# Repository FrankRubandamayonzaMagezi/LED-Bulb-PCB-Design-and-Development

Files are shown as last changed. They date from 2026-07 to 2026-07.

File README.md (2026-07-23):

# LED Bulb PCB Design and Development

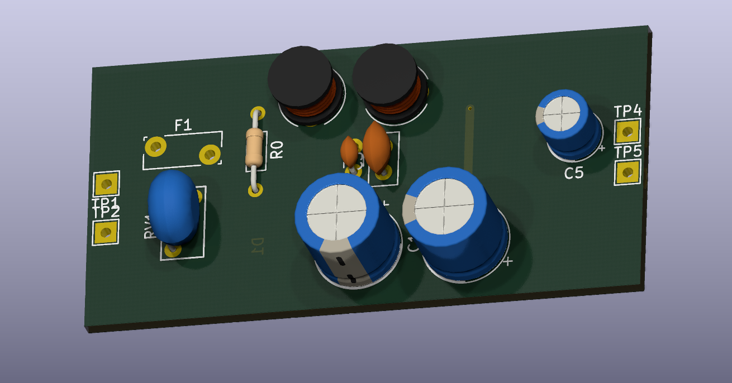
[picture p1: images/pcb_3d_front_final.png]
Final PCB 3D View


## Project Overview

This repository documents the design and development of a **5 W, 240 VAC LED bulb PCB**. The project follows the complete engineering workflow from schematic capture and PCB layout to simulation, PCB manufacturing, assembly and hardware testing.

The aim is to design an affordable, reliable and energy-efficient LED bulb suitable for indoor lighting while gaining practical experience in professional PCB design and electronics manufacturing.

---

## Project Objectives

The objectives of this project are to:

- Design a production-ready PCB for a 5 W LED bulb.
- Develop a complete schematic using KiCad.
- Assign footprints to all electronic components.
- Produce a manufacturable PCB layout.
- Simulate the LED bulb power supply using Proteus.
- Generate Gerber files for PCB fabrication.
- Manufacture and assemble the PCB.
- Test and evaluate the final LED bulb.
- Document every stage of the engineering process.

---

## Current Progress

- ✅ Schematic design completed
- ✅ Component footprint assignment completed
- ✅ PCB routing completed
- ✅ 3D PCB verification completed
- ✅ AC-to-DC bridge rectifier simulation completed
- ✅ Gerber generation
- 🔄 PCB fabrication (Training completed- LED bulb PCB fabrication in progress)
- 🔄 Component assembly
- ⏳ Hardware testing
- ⏳ Final product evaluation

---

## Design Specifications

- **Product:** 5 W LED Bulb
- **Input Voltage:** 240 VAC
- **Frequency:** 50 Hz
- **Application:** Indoor Lighting
- **PCB Design Software:** KiCad 10
- **Simulation Software:** Proteus 8 Professional

---

## Skills Demonstrated

This project demonstrates practical experience in:

- PCB schematic capture
- PCB layout design
- Component footprint assignment
- PCB routing
- Electrical Rule Check (ERC)
- Design Rule Check (DRC)
- PCB 3D verification
- Circuit simulation using Proteus
- Power electronics
- PCB fabrication techniques
- Electronics manufacturing
- Git and GitHub version control
- Engineering documentation

---

## Repository Structure

```
LED-Bulb-PCB-Design-and-Development/
│
├── docs/
├── fabrication/
├── footprints/
├── images/
├── pcb/
├── schematic/
├── simulations/
├── symbols/
├── README.md
└── .gitignore
```

---

## Design Workflow

The project follows the following engineering workflow:

1. Component selection
2. Schematic capture
3. Footprint assignment
4. Electrical Rule Check (ERC)
5. PCB layout
6. Component placement
7. PCB routing
8. Design Rule Check (DRC)
9. 3D PCB verification
10. Circuit simulation
11. Gerber generation
12. PCB fabrication
13. PCB assembly
14. Hardware testing
15. Final product evaluation

---

## Components Used

The current design includes:

- MP4050G LED Driver IC
- MB10S Bridge Rectifier
- Fuse
- Electrolytic Capacitors
- Ceramic Capacitors
- Resistors
- LEDs
- AC Input Connector
- PCB Connectors

---

## Proteus Simulation

A Proteus simulation was developed to demonstrate the **AC-to-DC rectification stage** of the LED bulb power supply.

The simulation includes:

- 240 VAC AC source
- Fuse
- Full bridge rectifier
- Electrolytic smoothing capacitor
- Current-limiting resistor
- LED load
- AC voltmeter
- DC voltmeter
- DC ammeter
- Oscilloscope

### Simulation Results

The following measurements were obtained during simulation:

- AC input voltage: **Approximately 241 VAC**
- DC output voltage: **Approximately 338 VDC**
- LED current: **Approximately 4.19 mA**

The simulation confirms successful AC-to-DC conversion and demonstrates the operation of the rectification stage.

> **Note**
>
> The production LED bulb uses the **MP4050G LED Driver IC**. Since a compatible Proteus simulation model is currently unavailable, the simulation focuses on demonstrating the AC-to-DC rectification stage rather than the complete LED driver circuit.

---

## Oscilloscope Waveform Verification

An oscilloscope was connected during the Proteus simulation to observe the AC input and the rectified DC output of the bridge rectifier. The captured waveforms verify the AC-to-DC conversion process by showing the sinusoidal AC input and the rectified DC output before filtering and after filtering. This confirms the correct operation of the bridge rectifier and smoothing capacitor before the power is supplied to the LED load.

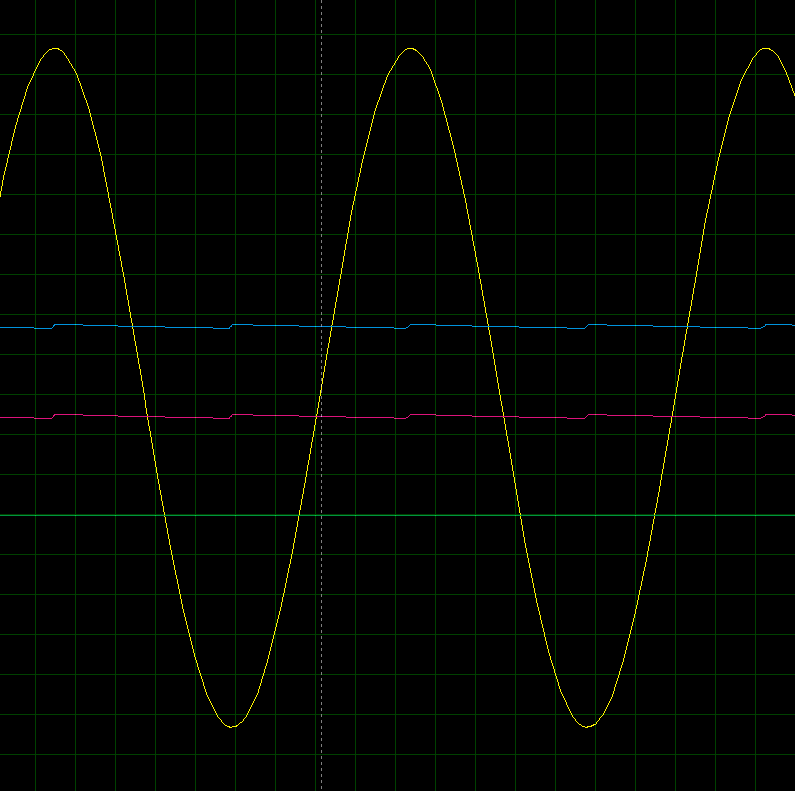
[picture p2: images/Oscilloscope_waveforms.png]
Oscilloscope Waveform Analysis


---

# Project Gallery

## Schematic Diagram

Complete schematic designed in KiCad.

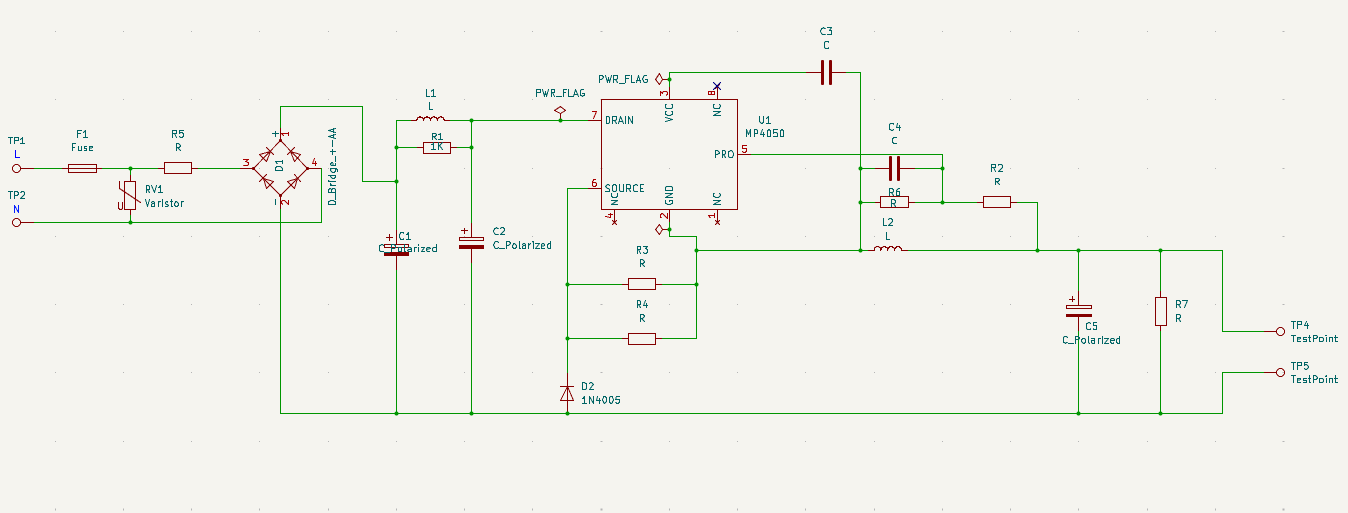
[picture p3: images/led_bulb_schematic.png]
Schematic


---

## Initial PCB Layout

First routed PCB layout.

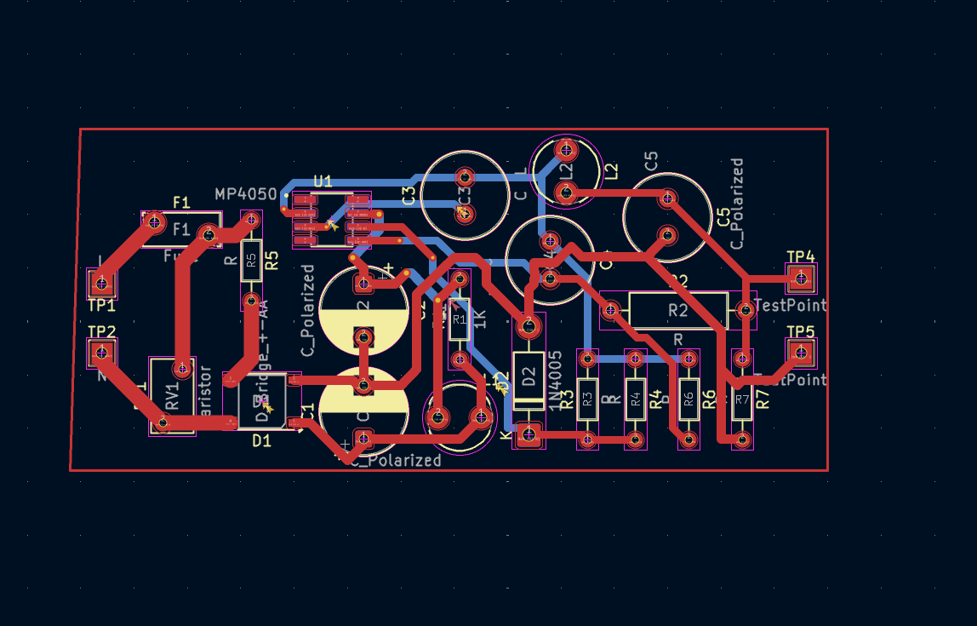
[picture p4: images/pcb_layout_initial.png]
Initial PCB Layout


---

## Final PCB Layout

Completed PCB routing ready for Gerber generation and fabrication.

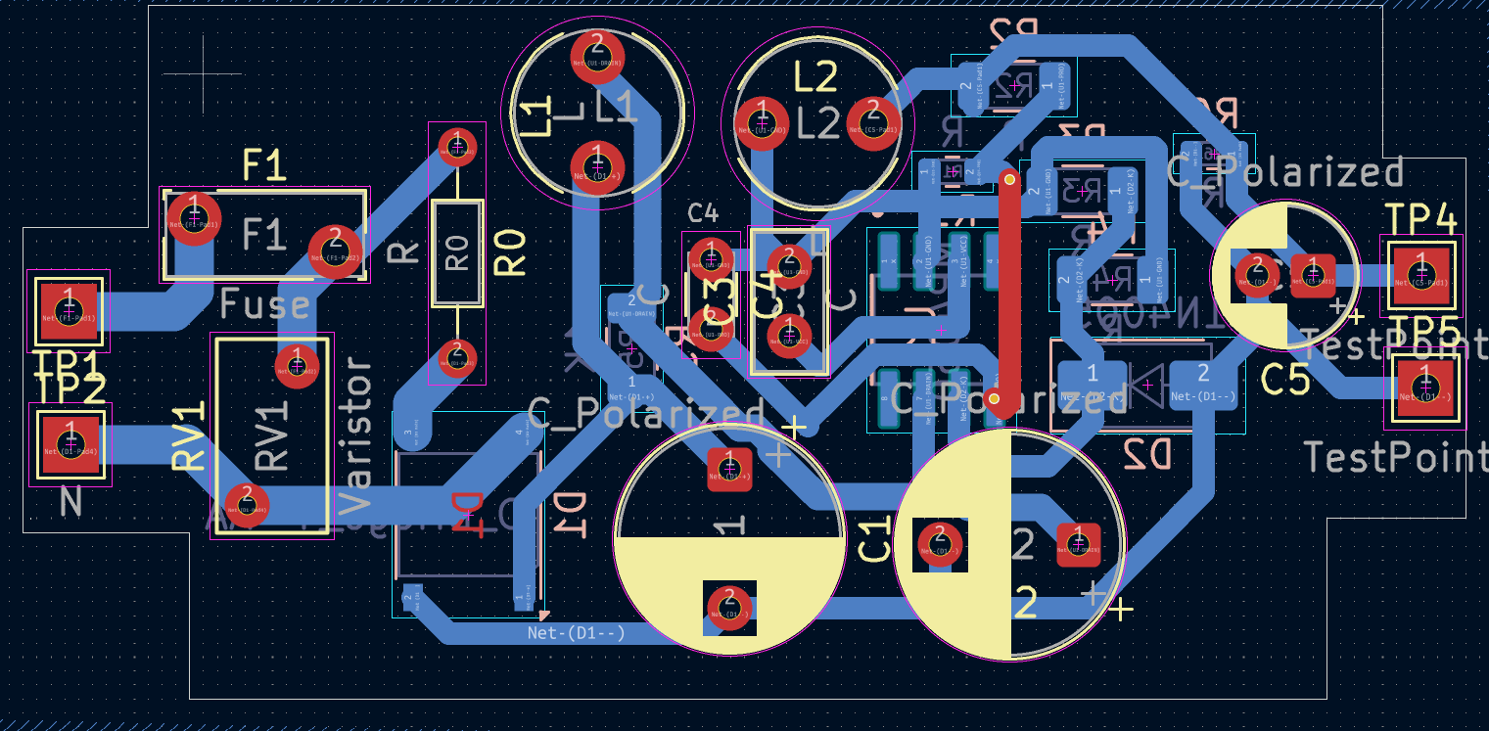
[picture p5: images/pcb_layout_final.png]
Final PCB Layout


---

## Initial 3D PCB View

Initial 3D visualization.

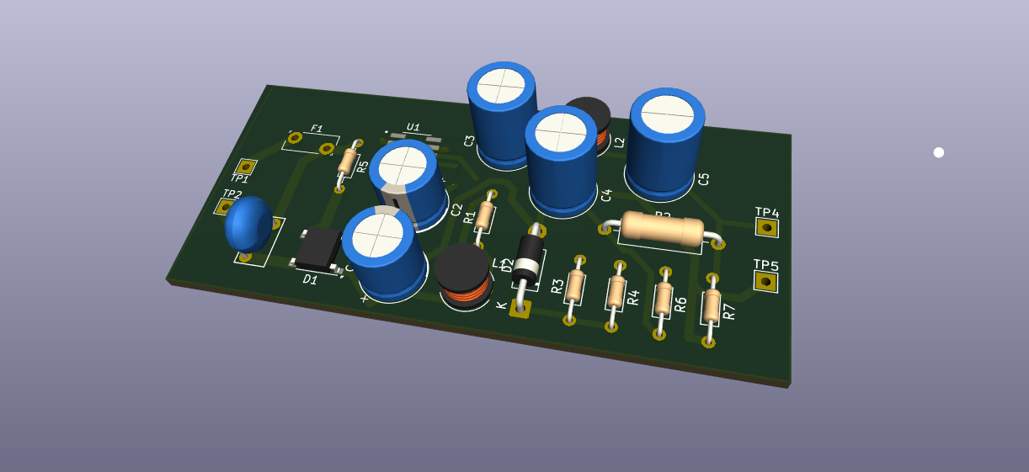
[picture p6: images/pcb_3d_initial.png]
Initial 3D PCB


---

## Final 3D PCB View (Front)

Completed PCB viewed from the component side.

Front 3D PCB

---

## Final 3D PCB View (Back)

Completed PCB viewed from the solder side.

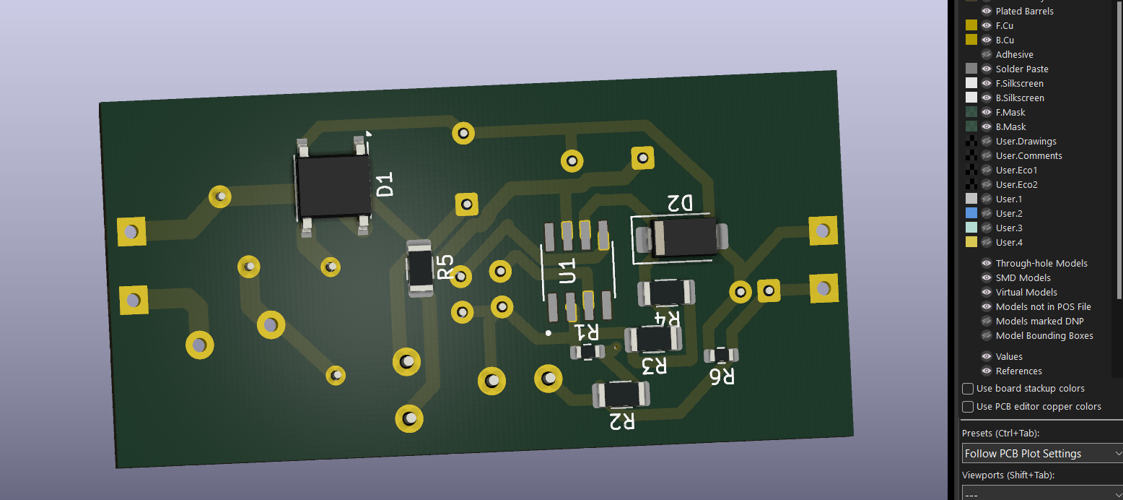
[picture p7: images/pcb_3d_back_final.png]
Back 3D PCB


---

## Proteus Simulation

Bridge rectifier simulation demonstrating AC-to-DC conversion.

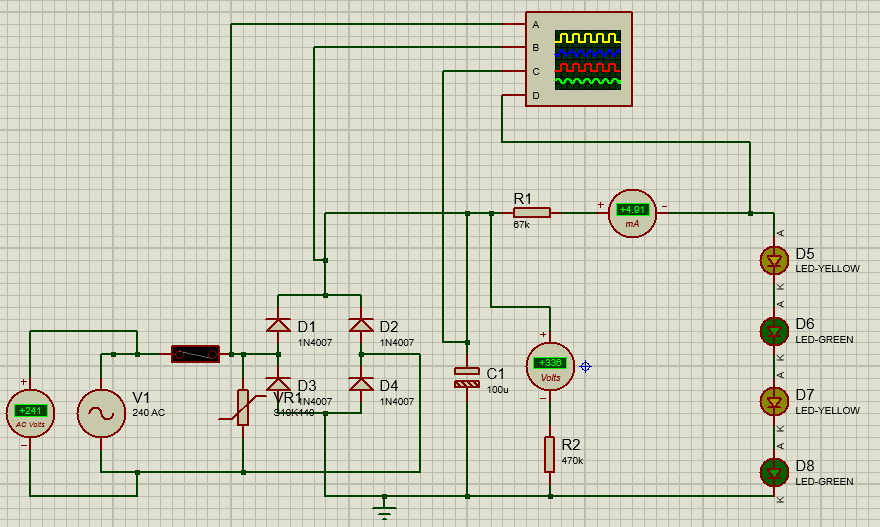
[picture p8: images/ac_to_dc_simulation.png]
Proteus Simulation


---

# PCB Fabrication Equipment

The fabrication process involves several specialized machines that support PCB production from raw copper-clad boards to finished printed circuit boards.

The following equipment will be used during the manufacturing process.

---

## PCB Prototyping Process

The PCB prototyping workflow illustrates the sequence of manufacturing steps used to transform the PCB design into a physical circuit board.

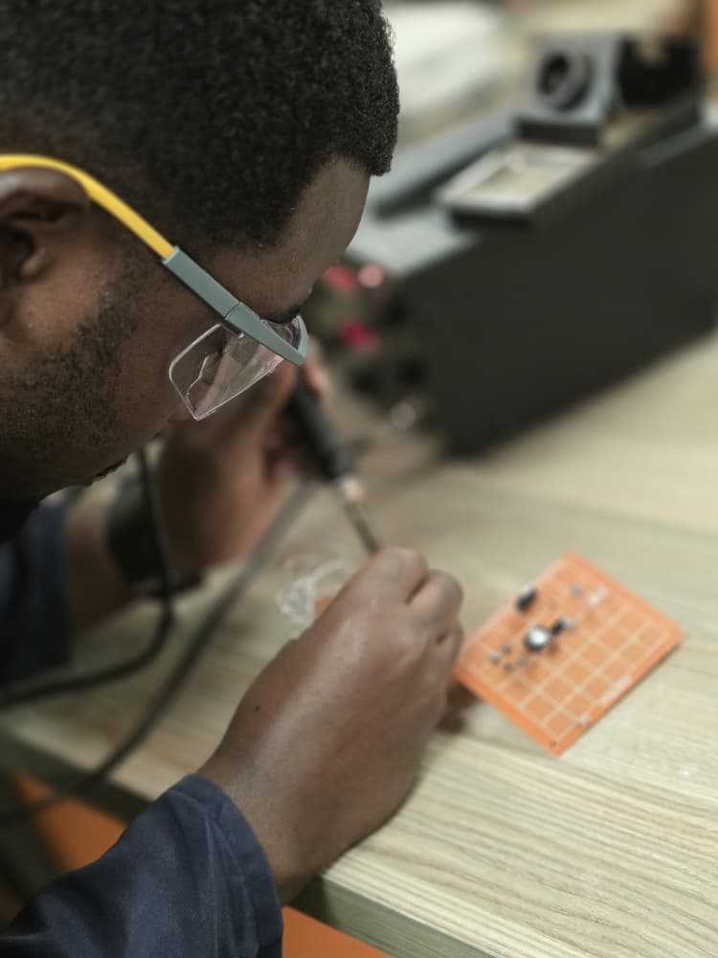
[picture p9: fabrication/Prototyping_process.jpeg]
PCB Prototyping Process


---

## Through-Hole PCB

Example of a through-hole PCB used during the fabrication and assembly process.

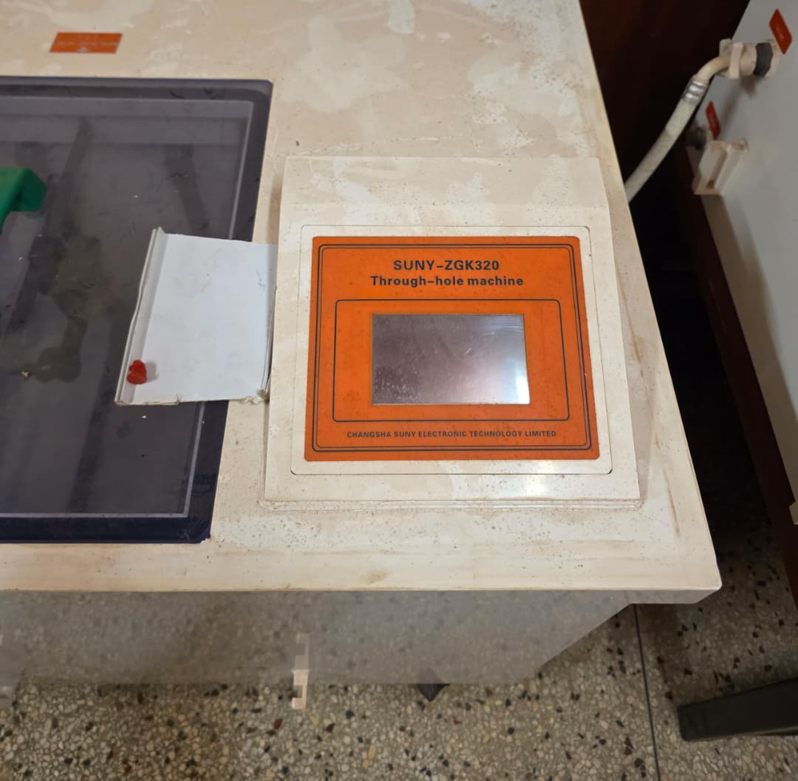
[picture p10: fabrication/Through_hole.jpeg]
Through-Hole PCB


---

## Through-Hole Drilling Machine

Machine used for drilling component mounting holes after PCB fabrication.

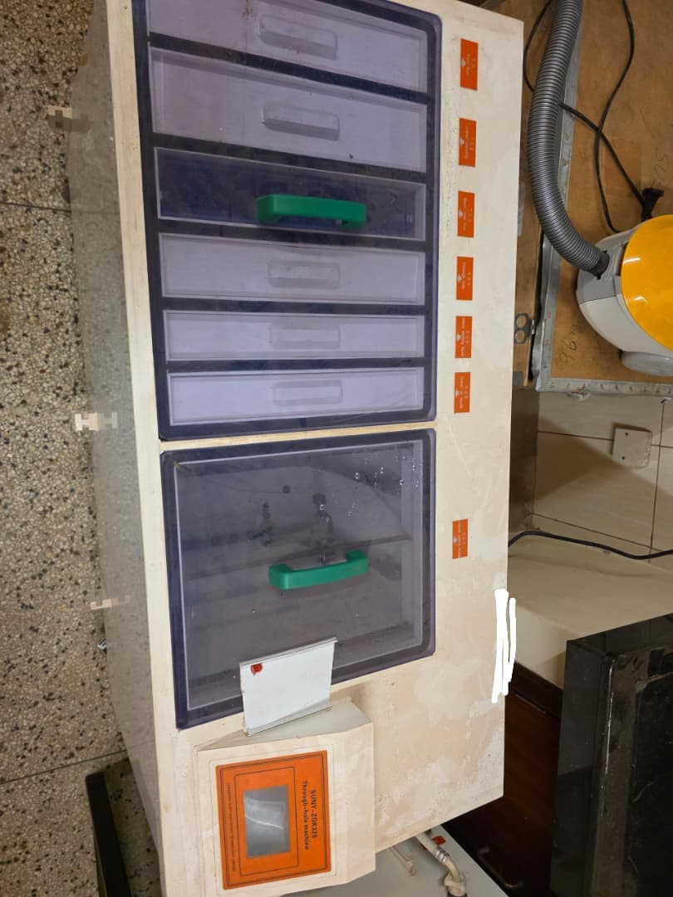
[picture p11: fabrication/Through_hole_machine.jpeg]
Through-Hole Drilling Machine


---

## Circuit Board Buffing Machine

Used to clean and polish the PCB surface before and after various fabrication processes, improving surface quality and solderability.

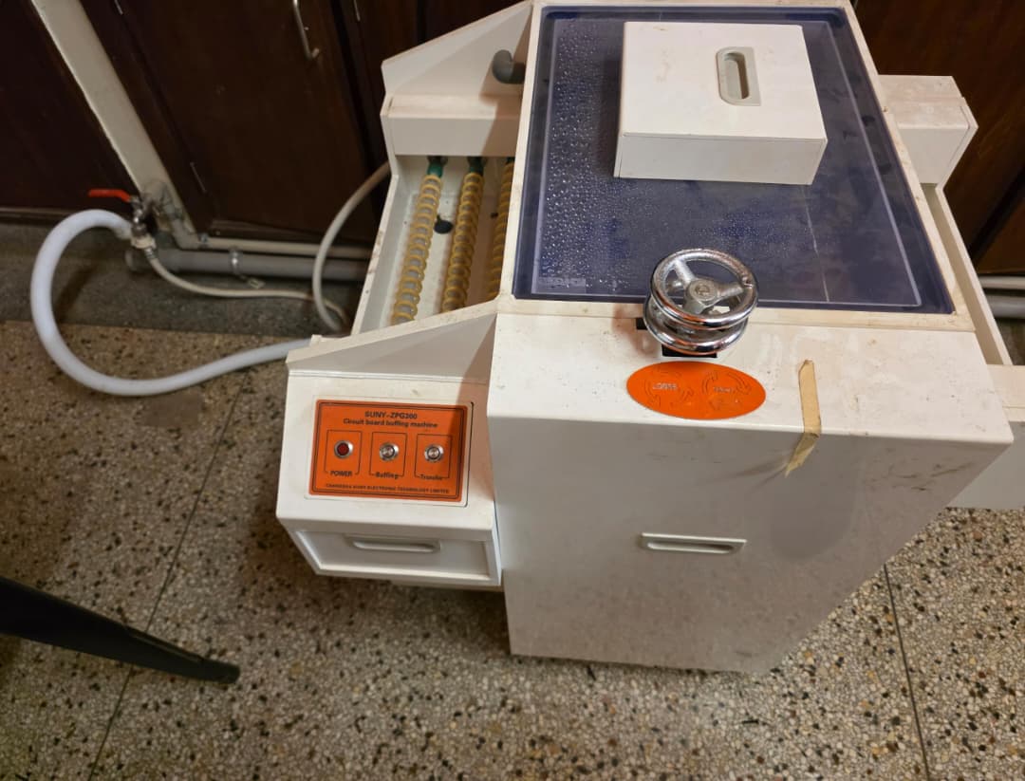
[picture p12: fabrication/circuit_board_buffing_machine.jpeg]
Circuit Board Buffing Machine


---

## Spray Stripping Machine

Used to remove photoresist after the PCB etching process, leaving the required copper traces on the board.

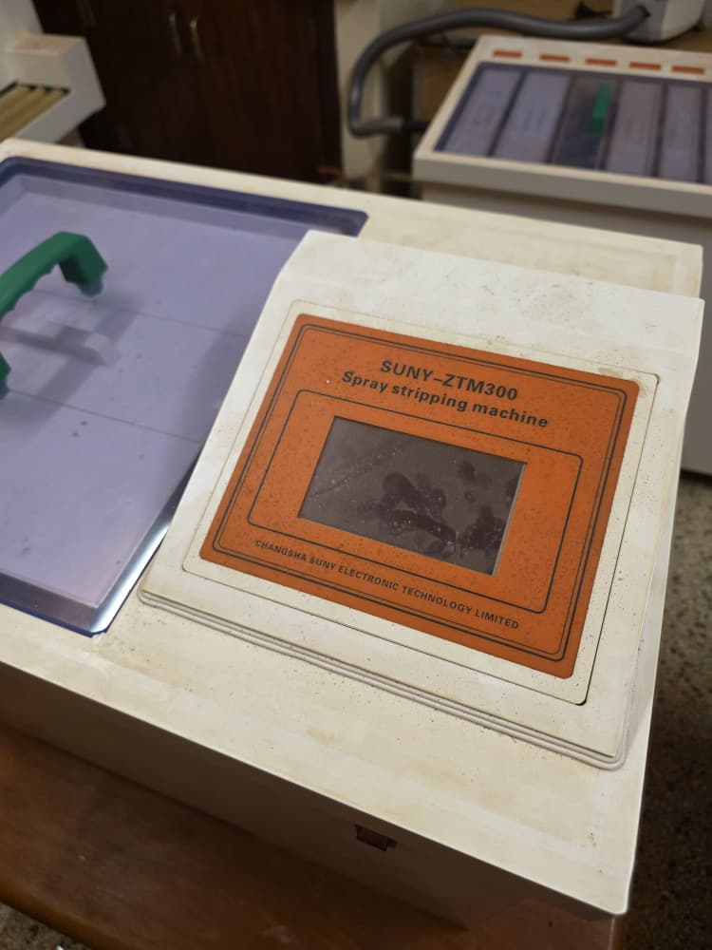
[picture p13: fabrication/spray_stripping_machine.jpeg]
Spray Stripping Machine


---

# PCB Fabrication Training

Before manufacturing the LED bulb PCB, practical PCB fabrication techniques were carried out using a **12 V to 5 V Buck Converter** as a training project. This provided hands-on experience with the complete PCB fabrication workflow and the operation of the equipment available in the PCB fabrication laboratory.

The objective was to understand how a PCB progresses from a digital design to a fully fabricated circuit board before applying the same techniques to the LED bulb project.

The fabrication process followed these stages:

- A single-layer copper-clad PCB was selected because the circuit required only one copper layer and no vias.
- The copper surface was thoroughly cleaned to remove contaminants and improve toner adhesion.
- The PCB layout was printed onto transfer paper and transferred onto the copper-clad board using the toner transfer method with heat and pressure.
- The board was immersed in Ferric Chloride solution to chemically etch away the exposed copper, leaving only the required PCB traces protected by the toner.
- The remaining toner was removed using ethanol, exposing clean copper tracks on the FR4 substrate.
- The fabricated PCB was then prepared for the remaining finishing processes, including drilling, solder mask application and silkscreen printing.

This practical exercise provided valuable experience in PCB fabrication techniques, chemical etching, surface preparation and manufacturing processes that will be applied during the fabrication of the 5 W LED bulb PCB developed in this repository.

## From Digital Design to Copper-Clad Board

The PCB fabrication process began by preparing a clean copper-clad board while referencing the digital PCB layout. This marked the transition from the computer-aided PCB design to the physical manufacturing process.

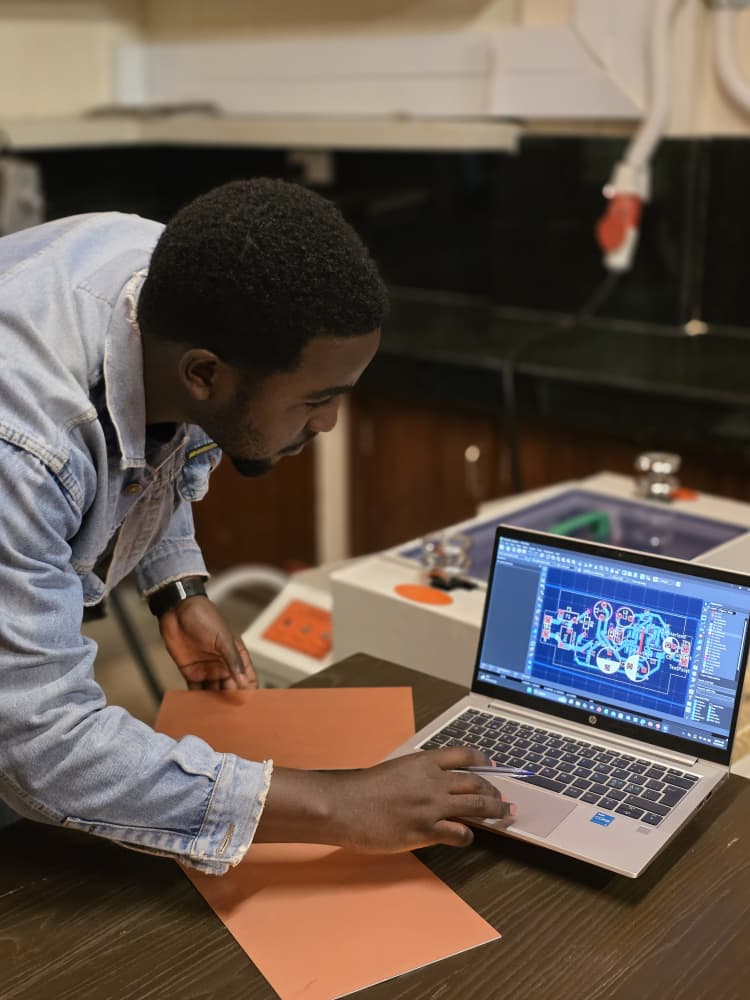
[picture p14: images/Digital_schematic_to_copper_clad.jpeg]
Digital Schematic to Copper Clad


---

## PCB with Toner Transfer

The PCB layout was transferred onto the cleaned copper-clad board using the toner transfer method. The toner formed a protective layer over the required copper traces before chemical etching.

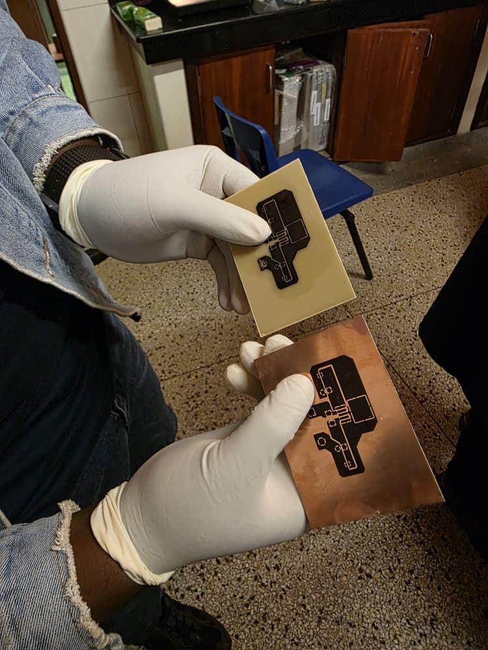
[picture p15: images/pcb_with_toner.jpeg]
PCB with Toner


---

## Ferric Chloride Etching

The board was immersed in a Ferric Chloride solution to dissolve the exposed copper while preserving the toner-protected PCB traces.

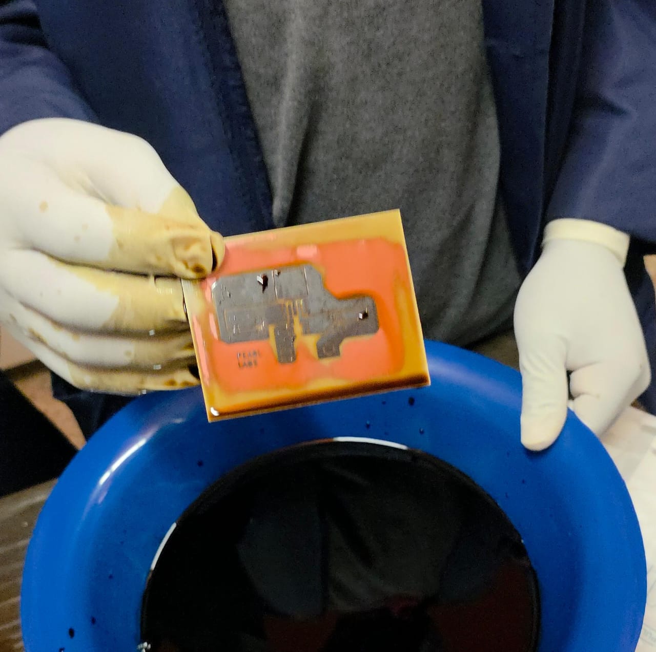
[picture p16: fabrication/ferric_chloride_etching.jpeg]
Ferric Chloride Etching


---

## PCB after Toner Removal

After chemical etching, the toner was removed using ethanol to expose the finished copper traces on the FR4 substrate. At this stage, the PCB pattern was fully formed and ready for drilling.

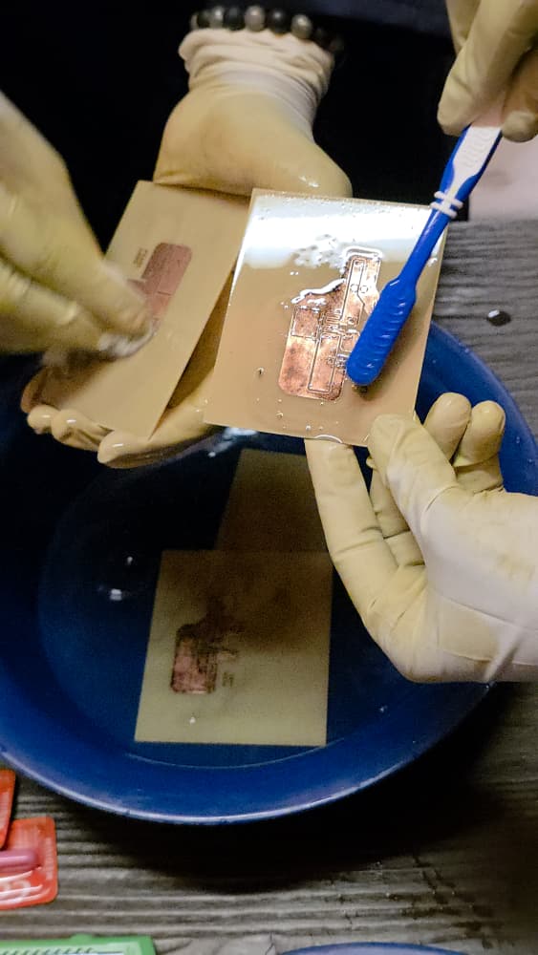
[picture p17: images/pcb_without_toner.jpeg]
PCB without Toner


---

## PCB Drilling

Component mounting holes were drilled at the required locations using a PCB drilling machine, preparing the board for component placement and soldering.

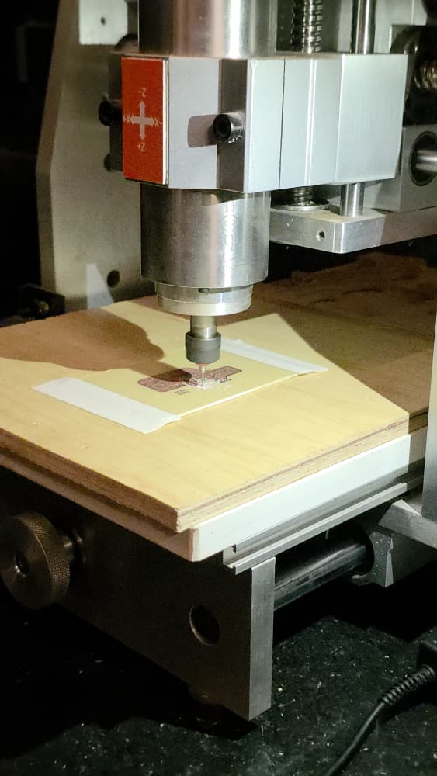
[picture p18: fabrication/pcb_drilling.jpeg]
PCB Drilling


---

## Heat Press Machine

A heat press machine was used during the toner transfer process to firmly bond the printed PCB artwork onto the copper-clad board. Proper heat and pressure ensured accurate transfer of the circuit pattern before chemical etching.

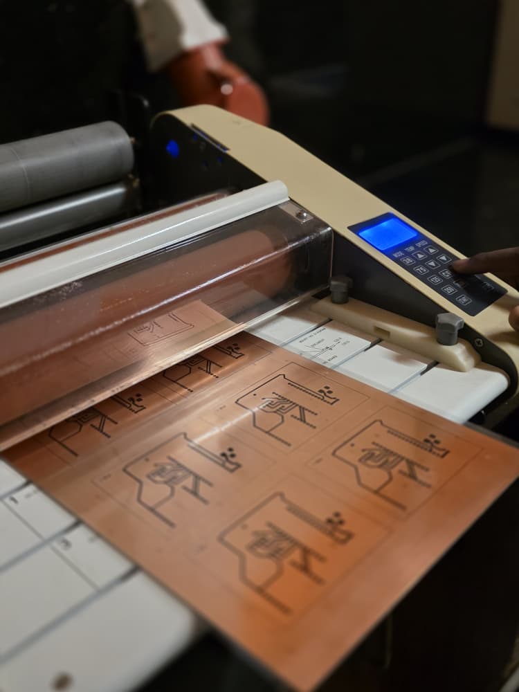
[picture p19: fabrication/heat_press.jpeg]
Heat Press


---
After chemical etching, the remaining toner was removed using ethanol to expose the finished copper traces on the FR4 substrate. At this stage, the PCB pattern had been successfully transferred onto the board and was ready for the remaining manufacturing processes.

The subsequent fabrication stages typically include:

- PCB drilling for through-hole components and mounting holes
- Surface cleaning and inspection
- Tin coating or surface finishing (where applicable) to protect exposed copper
- Solder mask application to insulate and protect the copper traces from oxidation and accidental short circuits
- Silkscreen printing to add component labels, reference designators and other markings
- Electrical continuity and quality inspection
- Component assembly and soldering
- Functional testing of the completed PCB

These finishing processes transform the etched PCB into a fully assembled and production-ready electronic circuit.
---

## Engineering Considerations

During the PCB design process, attention was given to:

- Proper component placement
- Efficient PCB routing
- Trace spacing
- Design for Manufacturability (DFM)
- Electrical Rule Check (ERC)
- Design Rule Check (DRC)
- PCB inspection using the KiCad 3D Viewer

---

## Future Work

The remaining stages of the project include:

- Generate Gerber files
- Manufacture the PCB
- Assemble the LED bulb
- Perform electrical testing
- Measure efficiency
- Evaluate thermal performance
- Produce final engineering documentation

---

## Learning Outcomes

Working on this project has provided practical experience in:

- PCB design using KiCad
- Circuit simulation using Proteus
- PCB routing techniques
- Power electronics
- Electronics manufacturing workflow
- Git and GitHub
- Engineering documentation

## License

This repository is shared for educational and portfolio purposes.

Please contact the repository owner before using any part of this design for commercial applications.

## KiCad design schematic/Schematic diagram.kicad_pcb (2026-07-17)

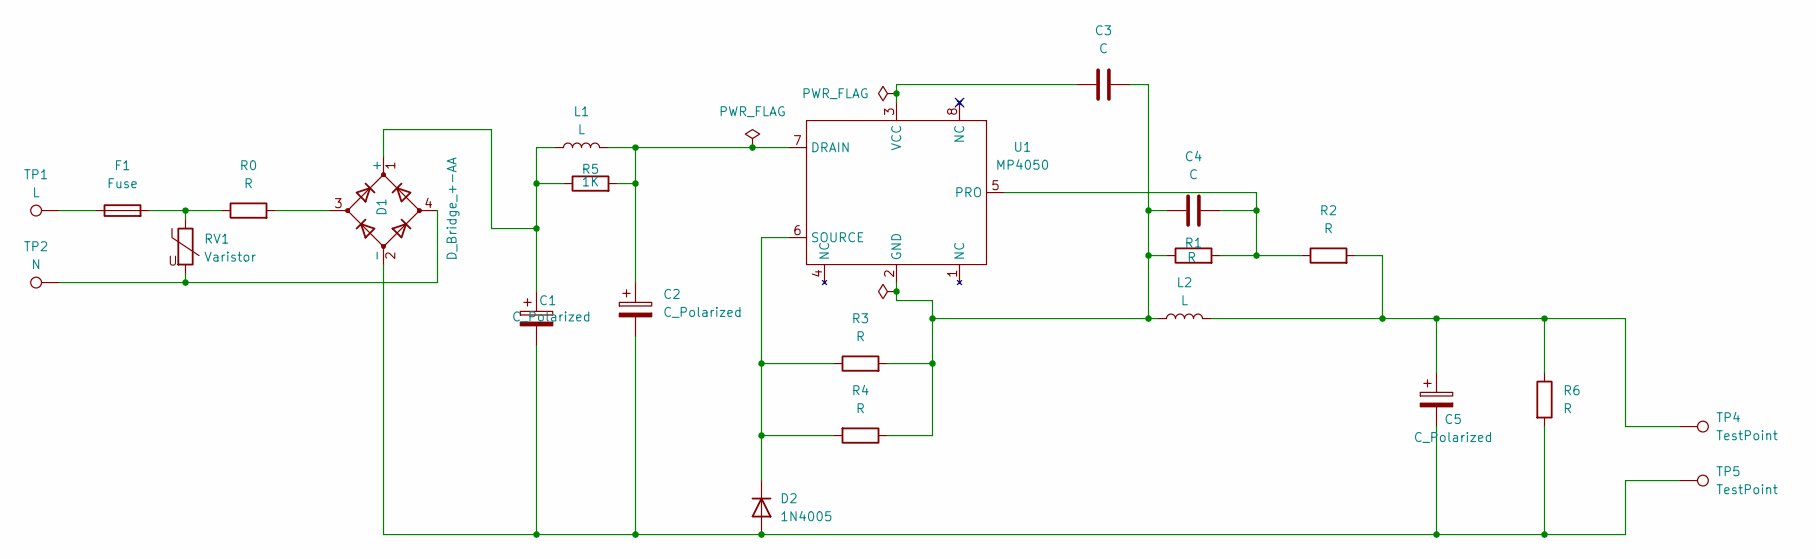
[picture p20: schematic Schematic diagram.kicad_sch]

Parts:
C1, C2: C_Polarized; CP_Radial_D8.0mm_P5.00mm
C3: C; C_Disc_D5.0mm_W2.5mm_P2.50mm
C4: C; C_Disc_D3.0mm_W1.6mm_P2.50mm
C5: C_Polarized; CP_Radial_D5.0mm_P2.00mm
D1: D_Bridge_+-AA; Diode_Bridge_Diotec_ABS
D2: 1N4005; D_SMA
F1: Fuse; Fuse_Bourns_MF-RG300
L1, L2: L; L_Radial_D6.0mm_P4.00mm
R0: R; R_Axial_DIN0204_L3.6mm_D1.6mm_P7.62mm_Horizontal
R1, R6: R; R_0603_1608Metric
R2, R3, R4: R; R_1206_3216Metric
R5: 1K; R_1206_3216Metric
RV1: Varistor; RV_Disc_D7mm_W4mm_P5mm
TP1: L; TestPoint_THTPad_2.0x2.0mm_Drill1.0mm
TP2: N; TestPoint_THTPad_2.0x2.0mm_Drill1.0mm
TP4, TP5: TestPoint; TestPoint_THTPad_2.0x2.0mm_Drill1.0mm
U1: MP4050; SOIC127P600X175-8N

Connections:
unnamed: C5.1, L2.2, R2.2, R6.1, TP4.1 (1_1)
unnamed: C1.1, D1.1 (+), L1.1, R5.1
unnamed: C1.2, C2.2, C5.2, D1.2 (-), D2.2 (A), R6.2, TP5.1 (1_1)
unnamed: D1.3, R0.2
unnamed: D1.4, RV1.2, TP2.1 (1_1)
unnamed: D2.1 (K), R3.1, R4.2, U1.6 (SOURCE)
unnamed: F1.1, TP1.1 (1_1)
unnamed: F1.2, R0.1, RV1.1
unnamed: C2.1, L1.2, R5.2, U1.7 (DRAIN)
unnamed: C3.2, C4.1, L2.1, R1.1, R3.2, R4.1, U1.2 (GND)
unnamed: C4.2, R1.2, R2.1, U1.5 (PRO)
unnamed: C3.1, U1.3 (VCC)

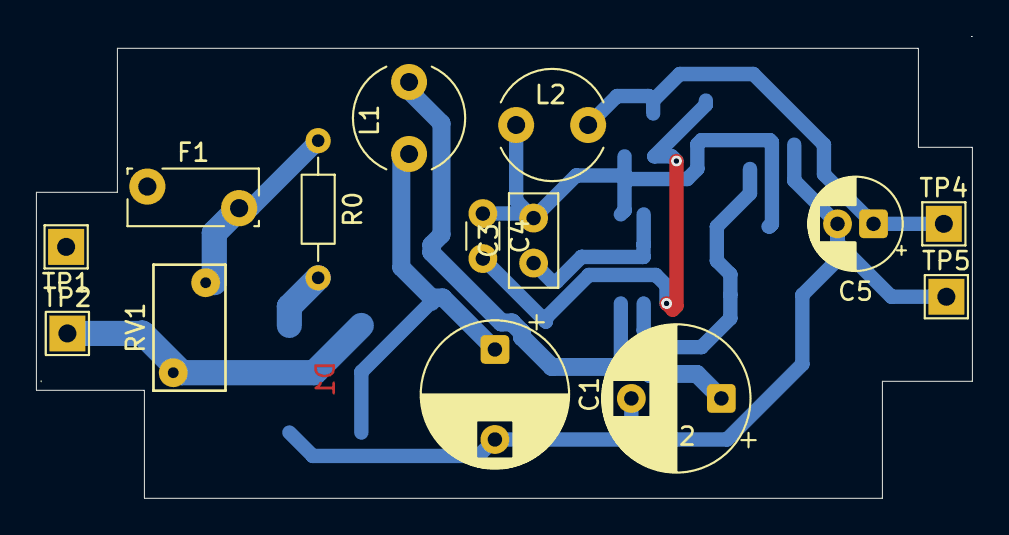
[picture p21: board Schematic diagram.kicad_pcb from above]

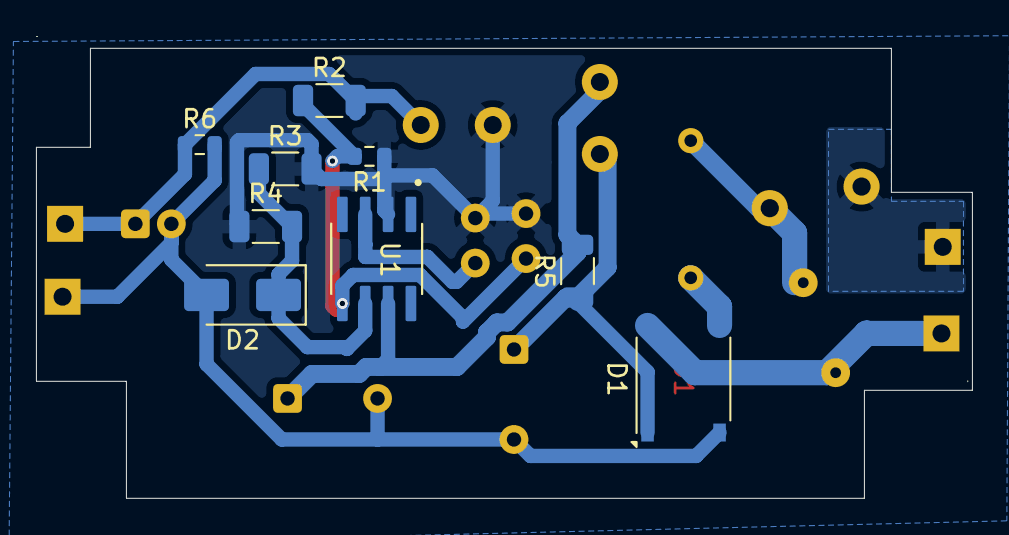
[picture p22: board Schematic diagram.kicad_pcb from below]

Board: 2 copper layers, 52.0 x 25.7 mm, 23 parts (9 on the bottom side), 12 nets.

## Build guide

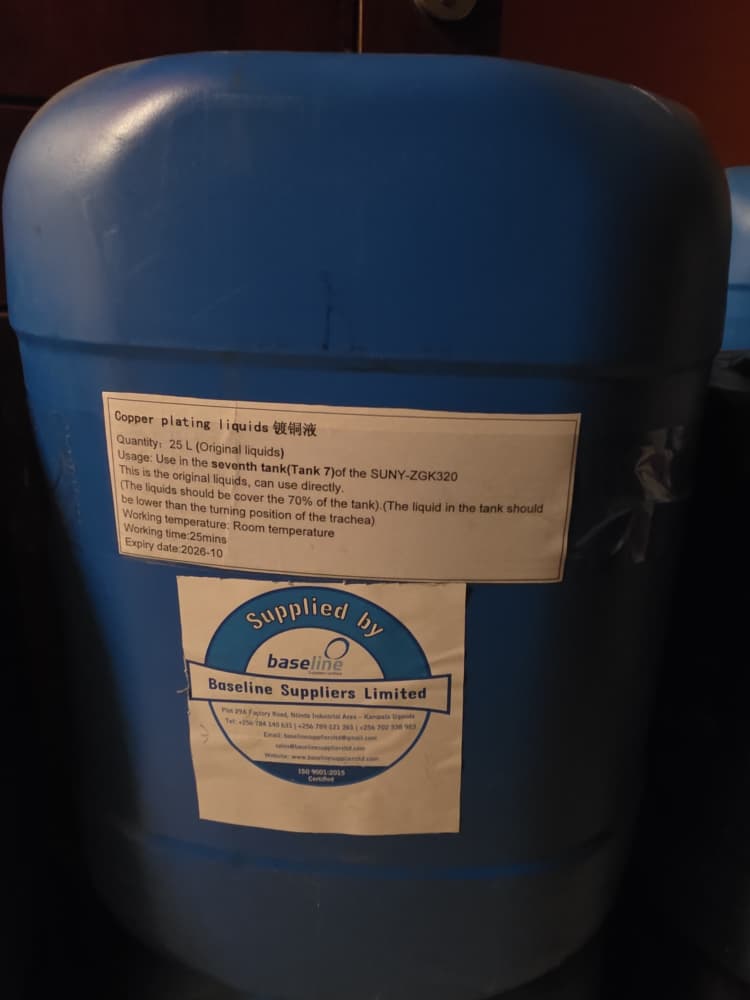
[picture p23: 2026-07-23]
fabrication/copper_plating_liquids.jpeg

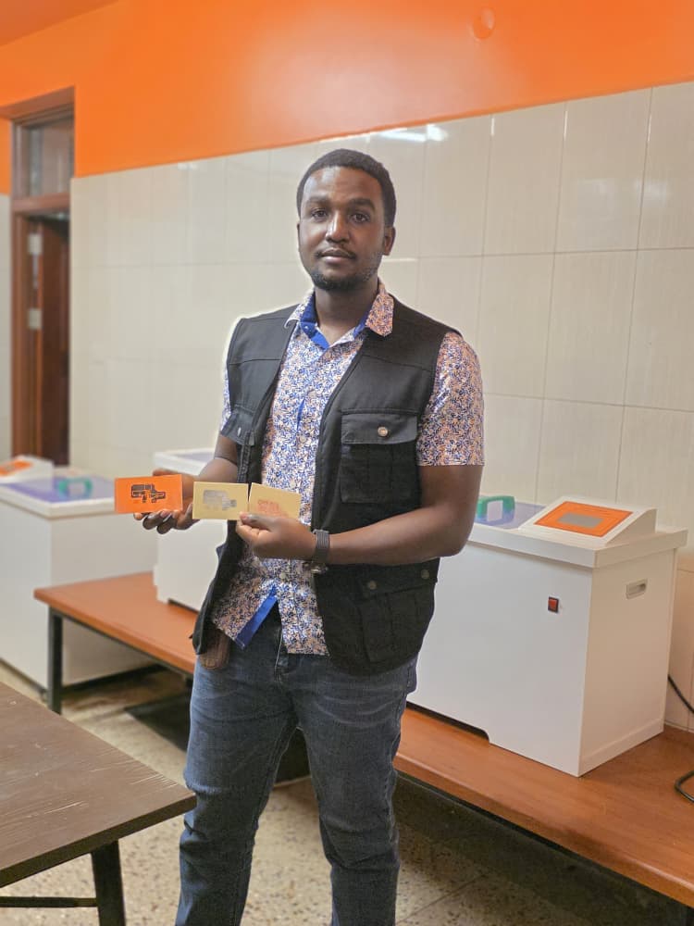
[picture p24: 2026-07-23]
fabrication/Boards.jpeg

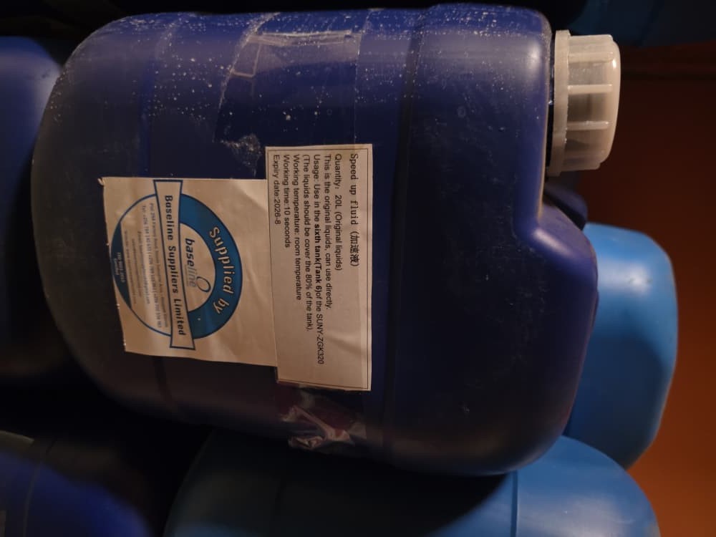
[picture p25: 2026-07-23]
fabrication/speed_up_fluid.jpeg

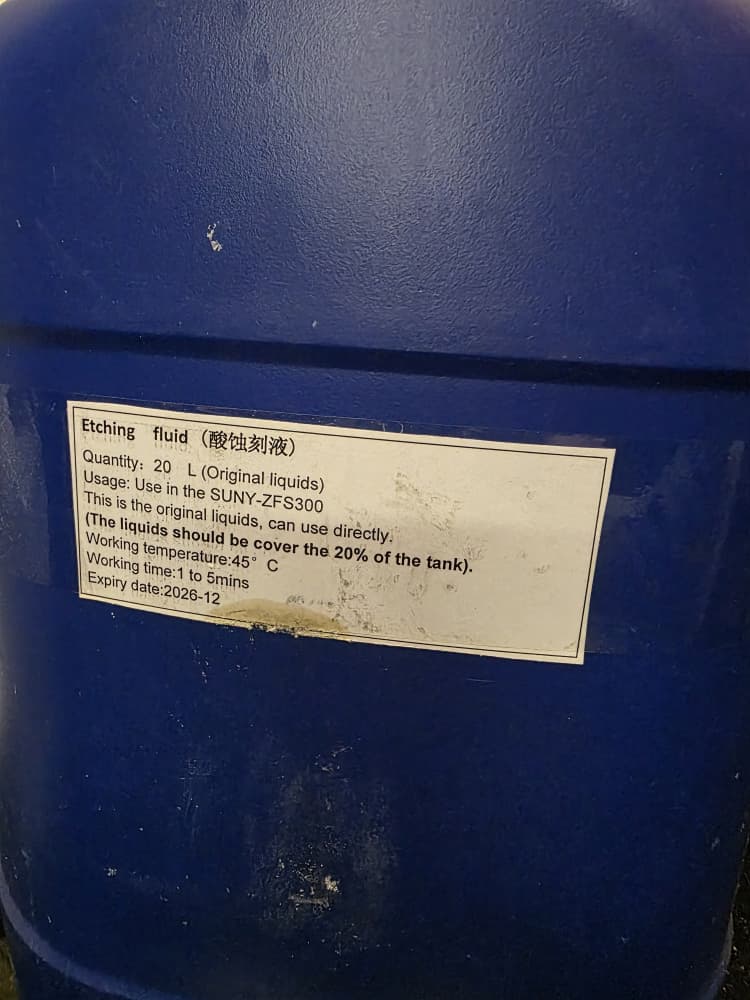
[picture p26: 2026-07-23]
fabrication/Etching_fluid.jpeg

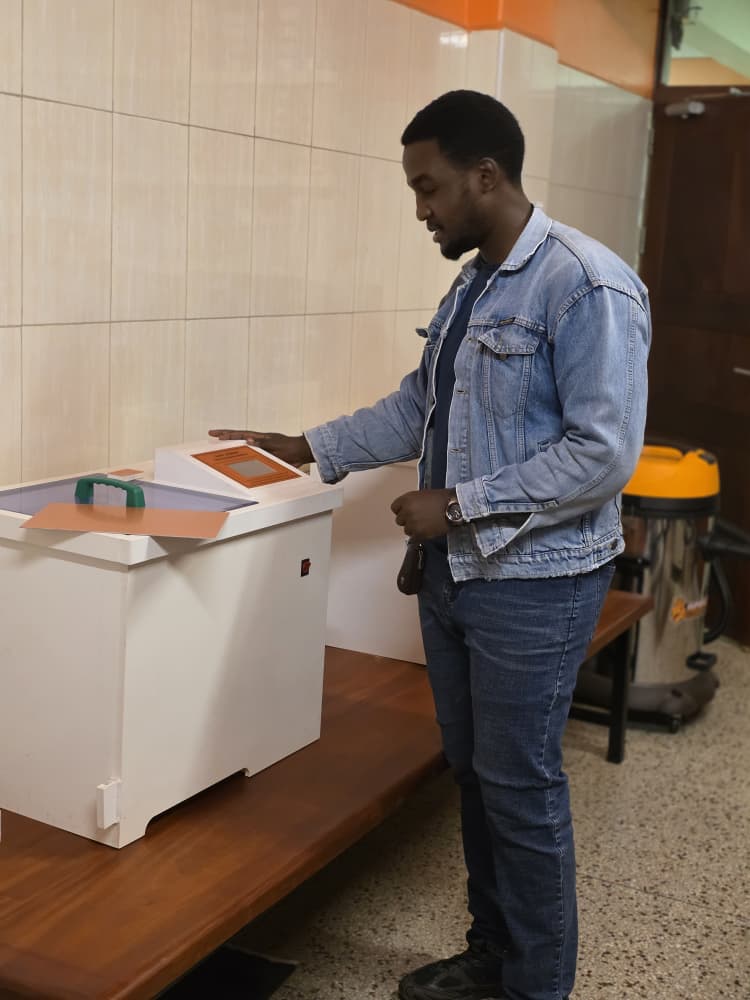
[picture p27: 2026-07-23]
fabrication/spray_stripping__machine.jpeg

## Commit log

2026-07-02 Initialize LED bulb PCB design repository
2026-07-02 Add initial LED bulb schematic design
    [Schematic diagram.kicad_pcb, Schematic diagram.kicad_sch]
2026-07-02 Update PCB routing and improve .gitignore
    [Schematic diagram.kicad_pcb]
2026-07-02 Update PCB routing and add LED schematic, layout and 3D images
    [Schematic diagram.kicad_pcb]
2026-07-03 I have made a simple AC to DC rectification simulation circuit showng the output at each stage and the LED Output
2026-07-03 Update PCB design and proteus bridge rectifier simulation
    [Schematic diagram.kicad_pcb, Schematic diagram.kicad_sch]
2026-07-03 Add new images of the FINAL LED 3d pcb render, results from protues simulation and FINAL layout
2026-07-17 Add PCB fabrication images and update KiCAD project
    [Schematic diagram.kicad_pcb]
